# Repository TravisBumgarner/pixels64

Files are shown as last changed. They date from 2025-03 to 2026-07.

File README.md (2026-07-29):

# Pixels64

Pixels64 is an 8x8 grid of 64 individually addressable RGB LEDs using the WS2812B package. It’s powered by an ESP32 running CircuitPython with the neopixel library for control. It features a custom-designed circuit board and a 3D-printable housing.

(Need help? [Join the community](https://discord.com/invite/J8jwMxEEff)!)

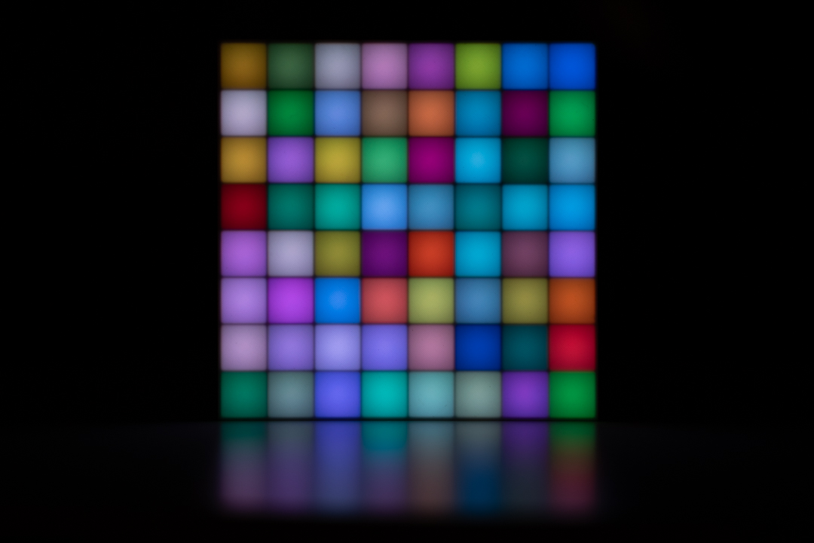
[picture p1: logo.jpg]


This repository includes all the files needed to build the Pixel64 display.

- `cad` - 3D models for housing
- `circuit` - PCB diagram and schematic
- `code` - Code for showing various displays
- `web` - Browser control UI, pairs with `bluetooth-experimental` over Web Bluetooth
- `displays` Collection of displays to get inspired. [Check them out on Instagram](https://www.instagram.com/pixelssixtyfour/).

Additionally

- `my_displays` - What I am currently tinkering on to display.

The PCB is designed to be modular, allowing multiple boards to be combined in an N x M configuration for any display size.

## Setup

### Tools

- Wire cutters
- Soldering Iron

### Components

- esp32
- Three different colors of wire (Red, Black, Blue)
- White Filament
- Black Filament
- 4x pixel64 Boards
- 16x M3x6x4.2 Brass Knurled Nuts
- 16x M3x5 Metal Screws

### Quick Setup

1. Print `base-plate.stl` and `walls.stl` in black. Print `case.stl` in white.
1. Upload files in `jlcpcb` and order from JLCPCB
1. Cut wire to length
   - 3x 25mm Red
   - 3x 25mm Blue
   - 3x 25mm Black
   - 1x 12mm Red
   - 1x 12mm Blue
   - 1x 12mm Black
1. Solder boards together.
   - Blue (data) goes to the center pad. Red (power) to the square pad. Black (power) to the circle pad.
   - Solder the short wires to the `DataIn1` of the first PCB.
   - Solder the long wires from `Dataout1` to the `DataIn1` of the next PCB.
   - Repeat the previous step two more times.
1. Use a soldering iron to press fit the brass knurled nuts into the risers on the `base-plate.stl`.
1. Screw in the boards.
   - Note that all of the boards are oriented with `DataIn1` at the bottom.
   - The arrangement of boards is
   ```
   3 4
   1 2
   ```
1. Setup virtual environment `python -m venv venv` inside the code directory
1. Use virtual environment `source venv/bin/activate
1. Install dependencies `pip install -r requirements.txt`
1. Setup device
   1. Wipe device `esptool.py --chip esp32 --port [device] erase_flash`
   1. [Download MicroPython](https://micropython.org/download/ESP32_GENERIC/) - Your device may be different.
   1. `esptool.py --chip esp32 --port [device] --baud 460800 write_flash -z 0x1000 file.uf2`
1. Run `write.sh` script to upload files to device.
1. Pres the `en` button to shuffle the displays.

## Additional Notes

### CAD

#### Case

- The `case.stl` services as the "screen" of the pixel64. It can be challenging to get a clean print of such a size. You'll need very good first layer adhesion. An alternative here would be to make a case out of white acrylic instead or cover the walls with a white sheet of paper.

### Code

#### Useful commands

- Get a list of connected devices
  - `ls /dev/cu.* /dev/tty.*`
  - The desired device should look something like `tty.usbserial-0001`
- Get a terminal to esp32
  - `mpremote`
  - Note - you can't use the `print` statement while uploading code.
  - Be sure to setup your Python virtual environment before running `mpremote`.
  - `ctrl + ]` to exit
  - `ctrl + c` and `ctrl + d` to soft reboot and cycle through displays.
- Send file to esp32
  - `ampy --port /dev/tty.usbserial-0001 put boot.py`
  - If `put` fails, reconnect device.
  - Push button with "en" to launch code.
- Remove a file
  - `ampy --port /dev/tty.usbserial-0001 rm boot.py`
- List files
  - `ampy --port /dev/tty.usbserial-0001 ls`

### Circuit

#### NeoPixel Mapping

The LED circuit board I designed supports multiple configurations, meaning the default ordering of NeoPixels may not match the expected layout. For example, setting neopixel[0] = (255, 255, 255) won't necessarily light up the top-left LED.

This script cycles through each pixel one at a time, allowing you to determine the actual order. Once identified, we can remap the ordering. For example, the physical layout might be:

```
 3  2  1  0
 7  6  5  4
11 10  9  8
15 14 13 12
```

We can then transform it into a more intuitive sequence:

```
 0  1  2  3
 4  5  6  7
 8  9 10 11
12 13 14 15
```

This remapping ensures easier indexing and consistent control over the LEDs.

Take the following code and save it to `main.py`

```
import machine
import time
import neopixel

NEO_PIXEL_PIN = 13
NEO_PIXEL_COUNT = 64

neo_pin = machine.Pin(NEO_PIXEL_PIN, machine.Pin.OUT)
np = neopixel.NeoPixel(neo_pin, NEO_PIXEL_COUNT)

def set_pixel(i, r, g, b):
    np[i] = (r, g, b)
    np.write()

def main():
    while True:
        for i in range(64):
            set_pixel(i, 255, 0, 0)
            time.sleep_ms(2000)
            set_pixel(i, 0, 0, 0)

if __name__ == "__main__":
    main()

```

Upload the code to the esp32

```
ampy --port [replace with your device] put main.py
```

Place a sheet of paper over the LEDs and tape in place.

Press the `en` button on the esp32 to run the code.

You should see the LEDs light up in a red color.

Mark the first LED that lights up as `0` and complete until done.

Now, starting from the top left, write the numbers of the LEDs in a left to right top to bottom order in the config.py file, replacing the variable `LOOKUP`.

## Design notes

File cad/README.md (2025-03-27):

# CAD

## V1.0 Initial Case Design

The parts were printed on printer with a max printing area of 220mm x 220mm.

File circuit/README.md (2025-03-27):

# Circuit

Each version has two folders inside. 
- `kicad` contains the KiCad project files.
- `jlcpcb` contains the files sent to JLCPCB for order.

## V1.0 Initial PCB Design 

Specs
- Dimension: 100mm x 100mm
- Layers 2
- PCB Thickness: 1.6mm
- PCB Color: Black

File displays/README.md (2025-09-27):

Check out the displays on Instagram: [pixelssixtyfour](https://www.instagram.com/pixelssixtyfour/).

# Displays

## display_gradient_squares

1. Fill display with 2x2 squares of random colors.
1. Repeat:
   1. Pick a random square
   1. Set a target color
   1. Create a gradient from current color to target color.

## display_random_pulses

1. Fill display with 1x1 squares of random colors.
1. Repeat:
   1. Pick a random square
   1. Set square to random color

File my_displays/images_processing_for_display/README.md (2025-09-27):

# Image Display System

This system converts square images into 8x8 color grids for display on your LED matrix.

## Setup

1. **Install Pillow** (for image processing):
   ```bash
   pip install Pillow
   ```

## Usage

### 1. Process Images

1. Place your square images in the `input/` directory
2. Supported formats: JPG, JPEG, PNG, BMP, GIF, TIFF
3. Run the processing script:
   ```bash
   cd src/images
   python3 process_images.py
   ```

This will:

- Resize each image to 8x8 pixels
- Extract RGB color data
- Generate `.py` files in the `output/` directory
- Create an `image_index.py` file listing all processed images

### 2. Display Images

The `display_images.py` file contains a `display_images()` function that:

- Automatically finds all processed images
- Cycles through them every 10 seconds
- Displays each image on your LED matrix

### 3. Integration

To use in your main display system, add this to your `main.py`:

```python
from images.display_images import display_images

displays_to_run = {
    "display_images": display_images,
    # ... other displays
}
```

## File Structure

```
images/
├── input/           # Put your source images here
├── output/          # Generated color data files
│   ├── __init__.py
│   ├── image_index.py  # Auto-generated list of images
│   └── *.py         # Individual image data files
├── process_images.py   # Image processing script
├── display_images.py   # Display function for MicroPython
└── README.md        # This file
```

## Image Processing Details

- Images are resized to 8x8 using high-quality LANCZOS resampling
- RGB values are extracted for each pixel
- Non-square images will be stretched to fit
- Color data is stored as tuples: `(r, g, b)` where each value is 0-255

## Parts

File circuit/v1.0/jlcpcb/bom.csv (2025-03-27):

Comment | Designator | Footprint | JLCPCB Part #
Capacitor_SMD:C_0805_2012Metric | C1,C2,C3,C4,C5,C6,C7,C8,C9,C10,C11,C12,C13,C14,C15,C16 | 0805 | C1711
LED_SMD:LED_WS2812B-Mini_PLCC4_3.5x3.5mm | D1,D2,D3,D4,D5,D6,D7,D8,D9,D10,D11,D12,D13,D14,D15,D16 | 3535 | C527089

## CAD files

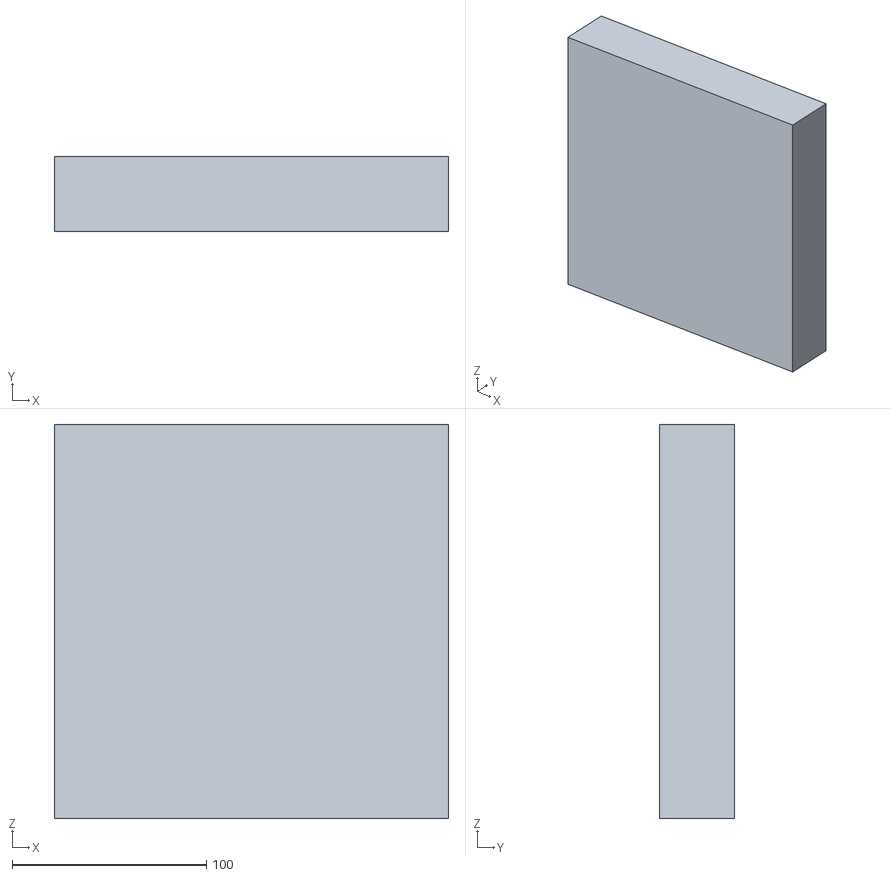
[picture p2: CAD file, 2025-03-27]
cad/v1.0/case.stl
203.0 x 38.5 x 203.0

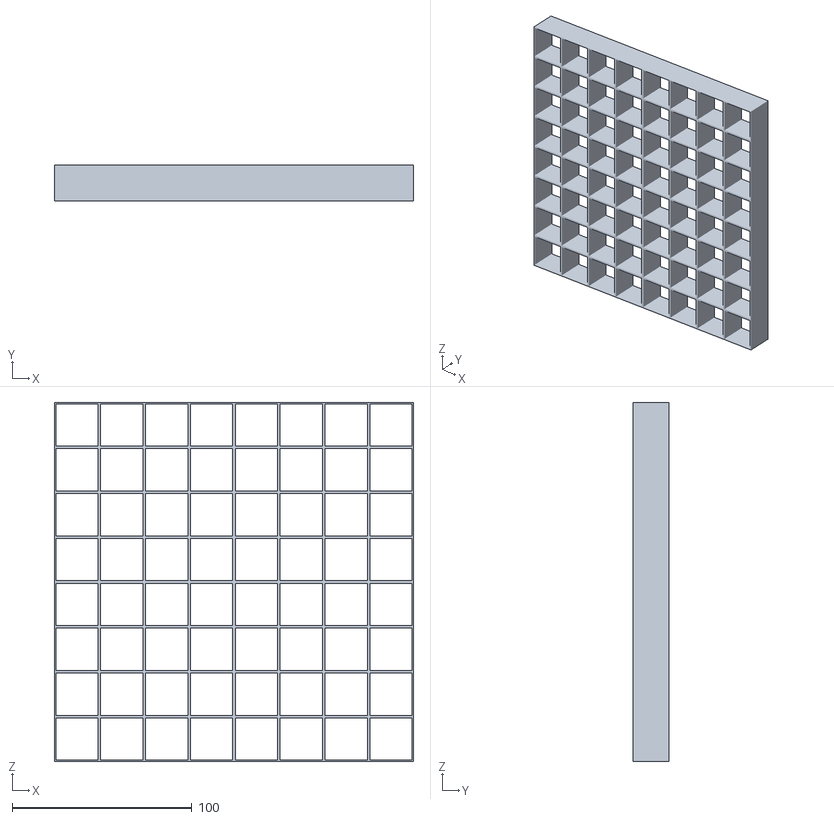
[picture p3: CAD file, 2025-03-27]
cad/v1.0/walls.stl
200.0 x 20.0 x 200.0

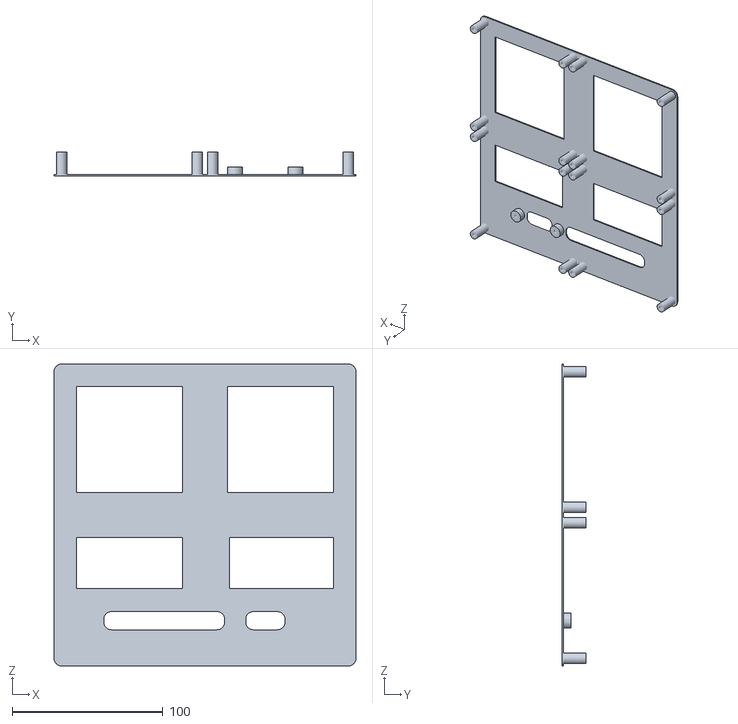
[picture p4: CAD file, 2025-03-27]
cad/v1.0/base-plate.stl
200.0 x 16.0 x 200.0

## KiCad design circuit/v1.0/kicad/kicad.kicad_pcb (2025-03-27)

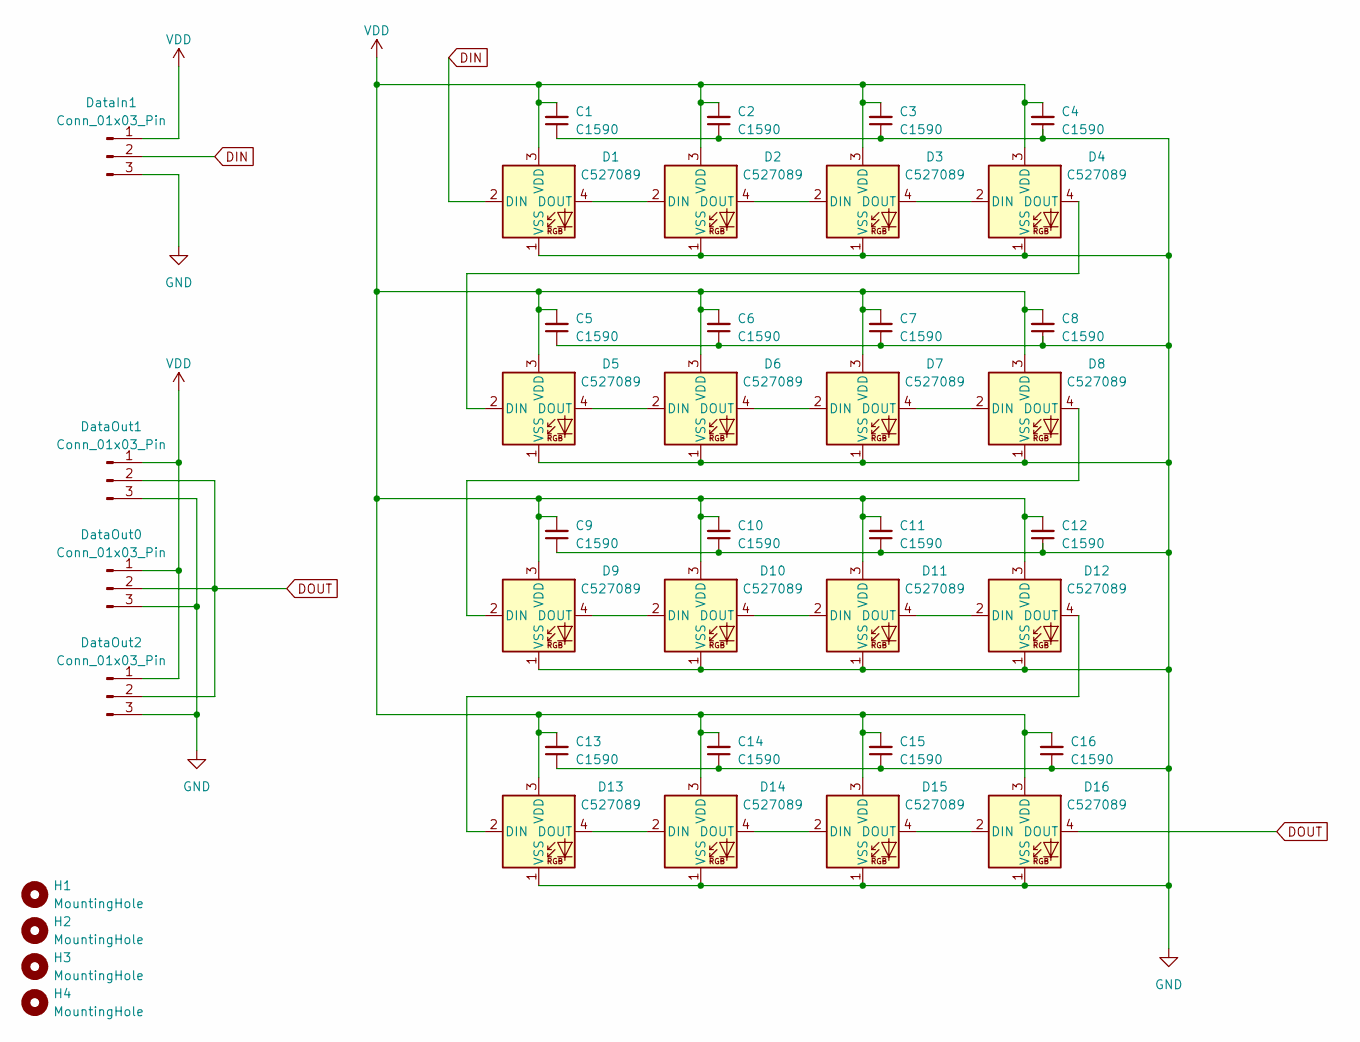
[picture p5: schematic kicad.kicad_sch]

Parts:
C1, C2, C3, C4, C5, C6, C7, C8, C9, C10, C11, C12, C13, C14, C15, C16: C1590; C_0805_2012Metric
D1, D2, D3, D4, D5, D6, D7, D8, D9, D10, D11, D12, D13, D14, D15, D16: C527089; LED_WS2812B-Mini_PLCC4_3.5x3.5mm
DataIn1: Conn_01x03_Pin; PinHeader_1x03_P2.54mm_Vertical
DataOut0, DataOut1, DataOut2: Conn_01x03_Pin; PinHeader_1x03_P2.54mm_Vertical
H1, H2, H3, H4: MountingHole; MountingHole_3.2mm_M3_DIN965_Pad

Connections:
DIN: D1.2 (DIN), DataIn1.2
DOUT: D16.4 (DOUT), DataOut0.2, DataOut1.2, DataOut2.2
GND: C1.1, C2.1, C3.1, C4.1, C5.1, C6.1, C7.1, C8.1, C9.1, C10.1, C11.1, C12.1, C13.1, C14.1, C15.1, C16.1, D1.1 (VSS), D2.1 (VSS), D3.1 (VSS), D4.1 (VSS), D5.1 (VSS), D6.1 (VSS), D7.1 (VSS), D8.1 (VSS), D9.1 (VSS), D10.1 (VSS), D11.1 (VSS), D12.1 (VSS), D13.1 (VSS), D14.1 (VSS), D15.1 (VSS), D16.1 (VSS), DataIn1.3, DataOut0.3, DataOut1.3, DataOut2.3
unnamed: D1.4 (DOUT), D2.2 (DIN)
unnamed: D2.4 (DOUT), D3.2 (DIN)
unnamed: D3.4 (DOUT), D4.2 (DIN)
unnamed: D4.4 (DOUT), D5.2 (DIN)
unnamed: D5.4 (DOUT), D6.2 (DIN)
unnamed: D6.4 (DOUT), D7.2 (DIN)
unnamed: D7.4 (DOUT), D8.2 (DIN)
unnamed: D8.4 (DOUT), D9.2 (DIN)
unnamed: D9.4 (DOUT), D10.2 (DIN)
unnamed: D10.4 (DOUT), D11.2 (DIN)
unnamed: D11.4 (DOUT), D12.2 (DIN)
unnamed: D12.4 (DOUT), D13.2 (DIN)
unnamed: D13.4 (DOUT), D14.2 (DIN)
unnamed: D14.4 (DOUT), D15.2 (DIN)
unnamed: D15.4 (DOUT), D16.2 (DIN)
VDD: C1.2, C2.2, C3.2, C4.2, C5.2, C6.2, C7.2, C8.2, C9.2, C10.2, C11.2, C12.2, C13.2, C14.2, C15.2, C16.2, D1.3 (VDD), D2.3 (VDD), D3.3 (VDD), D4.3 (VDD), D5.3 (VDD), D6.3 (VDD), D7.3 (VDD), D8.3 (VDD), D9.3 (VDD), D10.3 (VDD), D11.3 (VDD), D12.3 (VDD), D13.3 (VDD), D14.3 (VDD), D15.3 (VDD), D16.3 (VDD), DataIn1.1, DataOut0.1, DataOut1.1, DataOut2.1

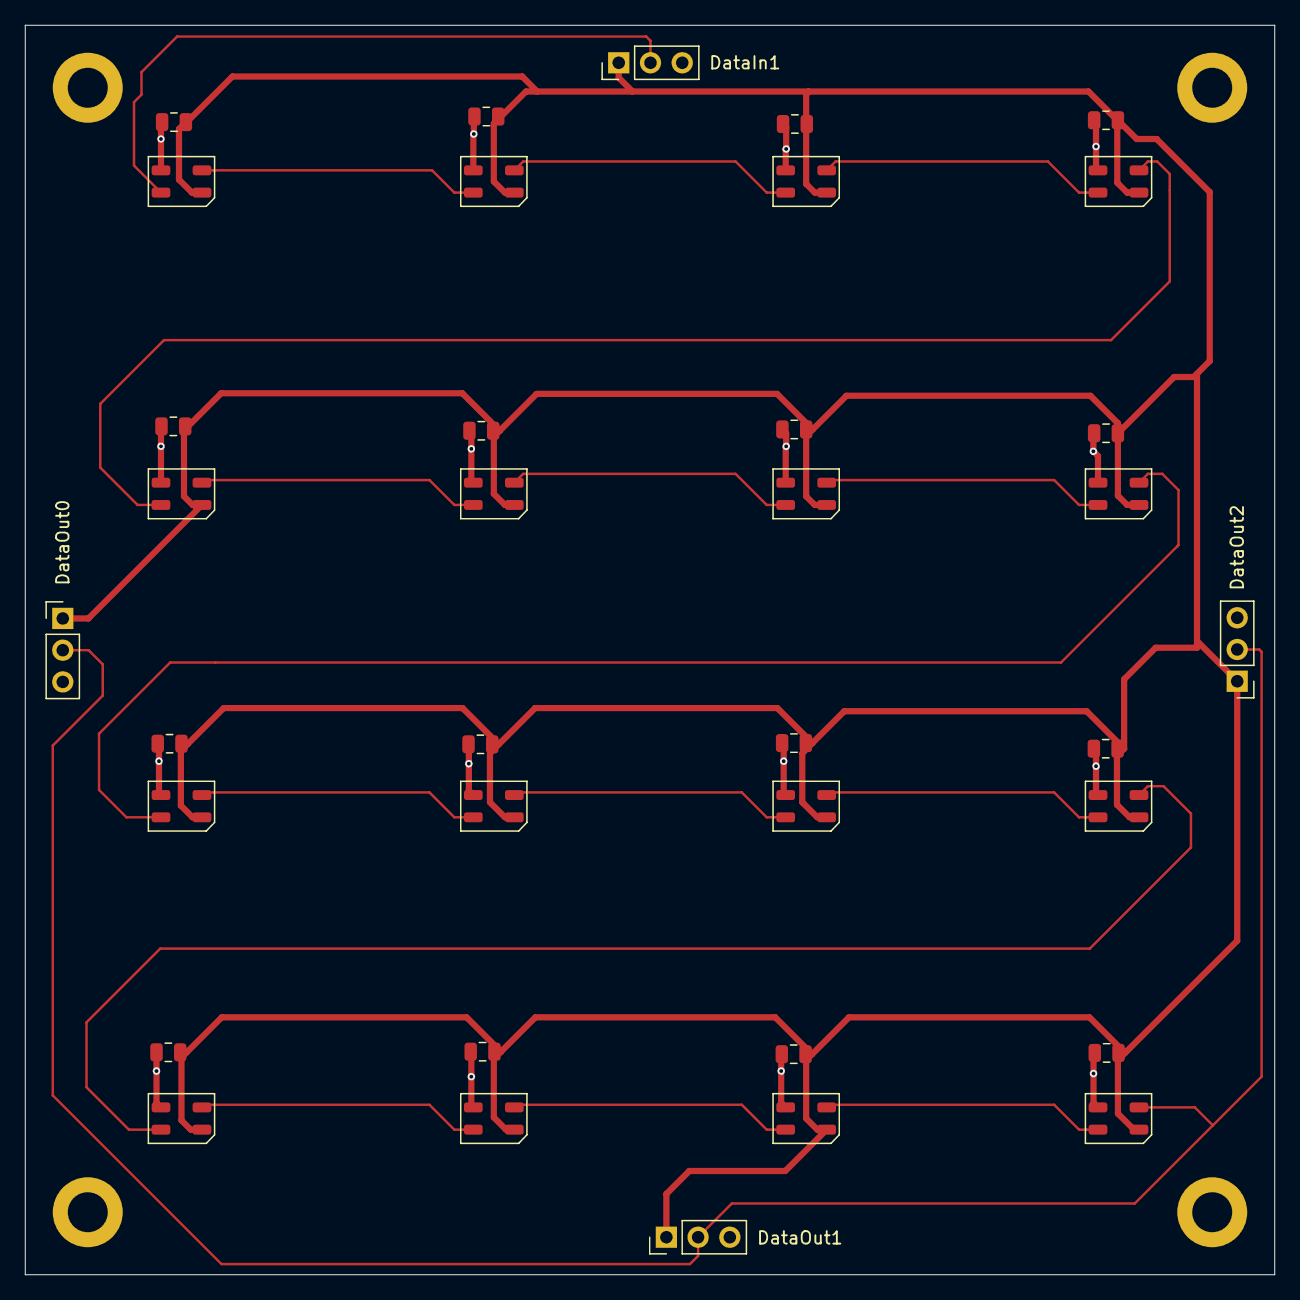
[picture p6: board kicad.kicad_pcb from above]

Board: 2 copper layers, 100.0 x 100.0 mm, 40 parts (0 on the bottom side), 19 nets.

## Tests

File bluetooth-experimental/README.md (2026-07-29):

# bluetooth-experimental

Bluetooth Low Energy (BLE) control for the Pixels64 8×8 NeoPixel display.

An ESP32 running MicroPython advertises a BLE service; a browser-based Web
Bluetooth UI connects to one or more boards and drives the LEDs in real time —
individual pixels, fills, brightness, and animated presets.

This replaces the earlier `wifi-experimental` sandbox (WiFi web server). BLE
avoids needing to put credentials on the device or share a network, and lets the
page talk to several displays at once.

## Layout

```
bluetooth-experimental/
├── src/
│   ├── boot.py       # runs on power-up; disables WiFi to free memory/radio
│   ├── config.py     # LED index lookup tables for the panel wiring
│   ├── presets.py    # animation classes (rainbow, chase, plasma, ...)
│   └── main.py       # BLE GATT server + render loop
├── test_pixel.py     # minimal sanity check — lights one pixel green
└── upload.sh         # flash src/*.py to the board via mpremote
```

This directory holds only the ESP32 firmware. The Web Bluetooth control UI that
drives the board lives in [`../web`](../web) — see
[Run the control UI](#run-the-control-ui) below.

## Requirements

- An ESP32 flashed with MicroPython (with the `bluetooth` module).
- A WS2812/NeoPixel 8×8 panel on GPIO **13**.
- `mpremote` for uploading (`pip install mpremote`).
- A browser that supports **Web Bluetooth** — Chrome or Edge on
  desktop/Android. Safari and iOS are **not** supported.

## Setup

```bash
cd bluetooth-experimental
python3 -m venv venv
source venv/bin/activate
pip install mpremote
```

## Upload firmware to the board

Connect the ESP32 over USB and adjust `PORT` in `upload.sh` if your device
isn't `/dev/tty.usbserial-0001`, then:

```bash
./upload.sh
```

This copies `boot.py`, `config.py`, `presets.py`, and `main.py` to the board and
resets it. On boot it advertises as **`Pixels64`** for a 10-second window
(`BLE_CONNECT_WINDOW_MS`) and lights pixel 0 as a status indicator:

| Indicator | Meaning |
|---|---|
| Green | Advertising, waiting for a connection |
| Blue | A client is connected |
| Red | BLE turned off (connection window expired or client disconnected) |

If no one connects within the window, BLE shuts off to save power. Power-cycle or
reset the board to advertise again. The last running preset is saved to
`active.json` and restored on the next boot.

## Run the control UI

The browser UI lives in [`../web`](../web). It's a single static file, so
serving it locally needs no toolchain:

```bash
cd web
npm run dev
```

`localhost` counts as a secure context, which the Web Bluetooth API requires —
no certificate needed. A LAN address would not work; in production the page sits
behind a reverse proxy that terminates TLS.

Open <http://localhost:8000> in Chrome or Edge (Safari does **not** support Web
Bluetooth), click **+ Add device**, and pick your `Pixels64` board from the BLE
chooser. You can add multiple boards. The UI provides a paintable 8×8 grid,
color picker, fill/clear, brightness and FPS sliders, and the preset list.

## BLE protocol

A single writable characteristic accepts short binary command packets. Service
and characteristic UUIDs are defined in `main.py`; the first byte is the opcode:

| Opcode | Name | Payload |
|---|---|---|
| `0x01` | SET_PIXEL | `idx, r, g, b` |
| `0x02` | FILL | `r, g, b` |
| `0x03` | CLEAR | — |
| `0x05` | PRESET | `index` (into `PRESET_ORDER`) |
| `0x06` | BRIGHTNESS | `0–255` |
| `0x07` | BATCH | `count`, then `count`×`idx,r,g,b`|
| `0x08` | STOP | — (stop the running animation) |
| `0x09` | FPS | `1–30` |

Pixel indices are logical positions (0–63, row-major); `config.py`'s `LOOKUP`
table maps them to the panel's physical wiring order.

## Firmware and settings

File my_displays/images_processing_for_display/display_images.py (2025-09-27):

import time
import machine
import neopixel
import sys

# Add parent directory to path to import config
sys.path.append("..")
from config import get_led_index

NEO_PIXEL_PIN = 13
NEO_PIXEL_COUNT = 64

neo_pin = machine.Pin(NEO_PIXEL_PIN, machine.Pin.OUT)
np = neopixel.NeoPixel(neo_pin, NEO_PIXEL_COUNT)

# ============================================================================
# PASTE GENERATED IMAGE DATA HERE (from generated_images.txt)
# ============================================================================

# Example placeholder - replace with your generated data
# Generated image data - Copy this into display_images.py
# Replace the existing IMAGES dictionary with this code:

# From 01-2022-06-05 11.48.28
a01_2022_06_05_11_48_28 = [
    [
        (46, 23, 16),
        (110, 70, 38),
        (164, 110, 55),
        (101, 66, 40),
        (121, 104, 96),
        (131, 117, 104),
        (140, 130, 119),
        (120, 108, 100),
    ],
    [
        (41, 33, 37),
        (126, 103, 95),
        (113, 84, 72),
        (89, 58, 44),
        (77, 50, 29),
        (123, 100, 84),
        (155, 137, 115),
        (144, 138, 128),
    ],
    [
        (24, 25, 32),
        (161, 143, 130),
        (171, 157, 145),
        (117, 98, 90),
        (57, 45, 51),
        (88, 73, 65),
        (80, 91, 89),
        (95, 75, 64),
    ],
    [
        (31, 11, 10),
        (145, 153, 154),
        (187, 195, 194),
        (123, 106, 100),
        (90, 45, 37),
        (85, 60, 48),
        (83, 68, 53),
        (57, 25, 15),
    ],
    [
        (22, 4, 3),
        (111, 96, 90),
        (164, 143, 134),
        (118, 103, 98),
        (80, 55, 30),
        (99, 88, 72),
        (69, 84, 72),
        (46, 22, 17),
    ],
    [
        (23, 17, 9),
        (93, 89, 85),
        (108, 107, 105),
        (114, 109, 107),
        (77, 73, 69),
        (81, 62, 55),
        (58, 49, 52),
        (54, 41, 36),
    ],
    [
        (24, 17, 9),
        (57, 57, 55),
        (101, 95, 92),
        (114, 104, 99),
        (66, 41, 37),
        (33, 16, 16),
        (78, 69, 62),
        (72, 61, 54),
    ],
    [
        (16, 9, 9),
        (47, 40, 39),
        (132, 117, 109),
        (89, 72, 63),
        (37, 17, 13),
        (26, 15, 14),
        (56, 66, 79),
        (58, 52, 51),
    ],
]

# From 03-000070120029
a03_000070120029 = [
    [
        (88, 79, 71),
        (102, 87, 83),
        (103, 100, 100),
        (99, 114, 118),
        (100, 127, 132),
        (105, 141, 143),
        (114, 153, 151),
        (116, 159, 154),
    ],
    [
        (91, 86, 86),
        (96, 99, 105),
        (98, 118, 130),
        (101, 136, 147),
        (110, 155, 161),
        (122, 172, 173),
        (137, 185, 180),
        (143, 192, 184),
    ],
    [
        (94, 97, 101),
        (95, 118, 128),
        (102, 131, 138),
        (111, 153, 159),
        (124, 175, 178),
        (138, 186, 181),
        (154, 197, 191),
        (159, 200, 193),
    ],
    [
        (95, 99, 94),
        (102, 152, 170),
        (122, 155, 150),
        (124, 161, 156),
        (133, 190, 192),
        (141, 185, 180),
        (160, 204, 200),
        (167, 211, 206),
    ],
    [
        (86, 59, 34),
        (86, 91, 84),
        (124, 121, 100),
        (160, 109, 56),
        (153, 117, 73),
        (156, 121, 74),
        (171, 133, 81),
        (161, 130, 84),
    ],
    [
        (86, 60, 39),
        (82, 54, 33),
        (100, 65, 36),
        (126, 80, 40),
        (123, 74, 34),
        (121, 73, 33),
        (118, 72, 32),
        (115, 69, 31),
    ],
    [
        (88, 60, 39),
        (90, 62, 42),
        (88, 61, 42),
        (85, 58, 41),
        (85, 59, 42),
        (85, 59, 43),
        (87, 59, 42),
        (88, 60, 43),
    ],
    [
        (93, 65, 45),
        (95, 68, 48),
        (90, 60, 43),
        (92, 61, 43),
        (93, 63, 44),
        (93, 64, 44),
        (93, 62, 43),
        (93, 62, 43),
    ],
]

# From 05-2022-09-14 18.13.48
a05_2022_09_14_18_13_48 = [
    [
        (71, 110, 135),
        (114, 141, 164),
        (148, 171, 193),
        (158, 180, 202),
        (156, 178, 201),
        (164, 189, 212),
        (164, 187, 207),
        (172, 196, 212),
    ],
    [
        (107, 135, 157),
        (134, 156, 178),
        (143, 164, 186),
        (181, 195, 208),
        (179, 194, 208),
        (169, 188, 205),
        (188, 203, 217),
        (177, 196, 211),
    ],
    [
        (92, 123, 146),
        (77, 115, 142),
        (135, 156, 176),
        (194, 201, 209),
        (168, 182, 196),
        (132, 155, 176),
        (97, 131, 158),
        (79, 118, 147),
    ],
    [
        (77, 111, 133),
        (62, 102, 126),
        (46, 92, 123),
        (59, 103, 134),
        (55, 99, 132),
        (27, 86, 121),
        (24, 83, 118),
        (31, 84, 117),
    ],
    [
        (101, 127, 148),
        (115, 135, 156),
        (112, 134, 155),
        (105, 130, 153),
        (108, 131, 153),
        (109, 133, 154),
        (107, 132, 153),
        (103, 127, 149),
    ],
    [
        (100, 125, 145),
        (98, 124, 145),
        (103, 126, 148),
        (108, 128, 150),
        (108, 129, 150),
        (111, 132, 153),
        (105, 128, 149),
        (95, 122, 143),
    ],
    [
        (92, 119, 140),
        (91, 120, 141),
        (89, 116, 139),
        (88, 116, 138),
        (88, 115, 138),
        (93, 119, 141),
        (86, 115, 137),
        (77, 109, 132),
    ],
    [
        (55, 93, 119),
        (68, 101, 126),
        (83, 112, 133),
        (86, 114, 136),
        (83, 111, 134),
        (82, 112, 133),
        (72, 105, 128),
        (66, 101, 125),
    ],
]

# From 04-DJI_0089
a04_DJI_0089 = [
    [
        (0, 112, 77),
        (0, 114, 73),
        (0, 116, 75),
        (0, 114, 74),
        (0, 112, 68),
        (1, 111, 69),
        (1, 110, 74),
        (0, 110, 80),
    ],
    [
        (0, 118, 79),
        (0, 118, 76),
        (0, 123, 79),
        (0, 119, 76),
        (1, 122, 79),
        (1, 118, 81),
        (1, 113, 75),
        (2, 111, 79),
    ],
    [
        (17, 126, 84),
        (12, 131, 82),
        (3, 135, 82),
        (0, 132, 80),
        (0, 131, 84),
        (1, 123, 84),
        (1, 116, 79),
        (3, 120, 84),
    ],
    [
        (51, 124, 86),
        (40, 128, 84),
        (26, 132, 84),
        (24, 140, 90),
        (18, 140, 91),
        (6, 129, 82),
        (5, 119, 83),
        (4, 119, 88),
    ],
    [
        (80, 127, 104),
        (54, 124, 87),
        (39, 123, 82),
        (26, 124, 81),
        (33, 130, 89),
        (29, 129, 89),
        (23, 125, 85),
        (19, 120, 86),
    ],
    [
        (186, 182, 174),
        (100, 132, 112),
        (38, 103, 68),
        (20, 98, 66),
        (23, 111, 81),
        (31, 117, 91),
        (36, 119, 87),
        (46, 124, 86),
    ],
    [
        (219, 214, 210),
        (209, 199, 192),
        (126, 138, 122),
        (63, 100, 75),
        (44, 94, 69),
        (37, 100, 77),
        (36, 110, 90),
        (41, 114, 91),
    ],
    [
        (187, 197, 202),
        (217, 213, 209),
        (223, 212, 203),
        (166, 165, 154),
        (101, 122, 104),
        (67, 105, 81),
        (47, 101, 82),
        (47, 108, 93),
    ],
]

# From 06-DSC_0711
a06_DSC_0711 = [
    [
        (118, 48, 1),
        (130, 56, 3),
        (143, 68, 23),
        (146, 73, 35),
        (141, 69, 26),
        (154, 77, 30),
        (161, 83, 35),
        (164, 89, 42),
    ],
    [
        (118, 48, 1),
        (128, 53, 0),
        (142, 67, 20),
        (145, 72, 34),
        (137, 63, 19),
        (150, 73, 24),
        (158, 80, 31),
        (157, 82, 35),
    ],
    [
        (117, 46, 1),
        (128, 52, 0),
        (140, 65, 19),
        (141, 68, 30),
        (132, 59, 13),
        (147, 70, 21),
        (153, 75, 26),
        (154, 79, 32),
    ],
    [
        (114, 45, 1),
        (124, 50, 0),
        (133, 60, 15),
        (136, 64, 24),
        (130, 58, 9),
        (139, 63, 13),
        (146, 69, 19),
        (147, 73, 26),
    ],
    [
        (109, 41, 1),
        (117, 45, 0),
        (120, 52, 10),
        (123, 55, 13),
        (122, 51, 2),
        (125, 55, 6),
        (136, 62, 11),
        (135, 64, 16),
    ],
    [
        (100, 37, 2),
        (103, 36, 0),
        (120, 63, 22),
        (152, 114, 72),
        (134, 87, 46),
        (115, 50, 6),
        (127, 57, 6),
        (121, 55, 7),
    ],
    [
        (90, 31, 2),
        (90, 29, 0),
        (111, 60, 25),
        (126, 85, 51),
        (99, 41, 10),
        (109, 44, 1),
        (115, 51, 3),
        (109, 49, 3),
    ],
    [
        (79, 25, 1),
        (84, 29, 1),
        (81, 27, 1),
        (79, 23, 0),
        (90, 31, 0),
        (101, 41, 1),
        (105, 45, 1),
        (100, 45, 2),
    ],
]

# From 01-DJI_0276
a01_DJI_0276 = [
    [
        (74, 146, 208),
        (62, 139, 203),
        (53, 132, 199),
        (46, 126, 194),
        (39, 121, 189),
        (31, 115, 184),
        (26, 111, 179),
        (25, 110, 177),
    ],
    [
        (99, 164, 220),
        (85, 156, 216),
        (72, 148, 212),
        (61, 141, 206),
        (54, 135, 202),
        (50, 131, 198),
        (47, 128, 195),
        (43, 125, 192),
    ],
    [
        (128, 183, 230),
        (118, 178, 228),
        (105, 171, 224),
        (98, 170, 224),
        (88, 164, 221),
        (75, 153, 212),
        (70, 148, 209),
        (66, 144, 206),
    ],
    [
        (178, 221, 253),
        (169, 216, 250),
        (162, 214, 250),
        (142, 194, 231),
        (131, 186, 226),
        (140, 200, 241),
        (130, 190, 234),
        (124, 185, 230),
    ],
    [
        (137, 158, 175),
        (144, 163, 179),
        (146, 165, 180),
        (113, 129, 143),
        (116, 133, 146),
        (157, 173, 182),
        (154, 170, 179),
        (153, 169, 178),
    ],
    [
        (103, 103, 101),
        (116, 112, 108),
        (122, 118, 114),
        (123, 120, 115),
        (130, 126, 120),
        (143, 139, 132),
        (144, 141, 134),
        (134, 133, 129),
    ],
    [
        (134, 132, 127),
        (148, 145, 139),
        (155, 152, 147),
        (149, 142, 133),
        (148, 140, 129),
        (154, 146, 132),
        (157, 147, 130),
        (137, 131, 119),
    ],
    [
        (157, 158, 152),
        (151, 149, 142),
        (152, 147, 138),
        (168, 163, 153),
        (166, 162, 152),
        (161, 154, 140),
        (160, 153, 136),
        (155, 147, 129),
    ],
]

# From 02-Foto-21
a02_FOTO_21 = [
    [
        (22, 24, 19),
        (21, 24, 19),
        (41, 40, 43),
        (72, 63, 85),
        (65, 59, 81),
        (110, 102, 126),
        (189, 182, 193),
        (212, 205, 211),
    ],
    [
        (65, 61, 69),
        (51, 50, 54),
        (62, 58, 69),
        (65, 60, 81),
        (58, 56, 76),
        (51, 47, 67),
        (127, 124, 138),
        (187, 181, 191),
    ],
    [
        (95, 91, 104),
        (82, 79, 92),
        (60, 61, 69),
        (97, 92, 103),
        (98, 92, 99),
        (181, 169, 172),
        (246, 229, 233),
        (233, 218, 222),
    ],
    [
        (119, 114, 128),
        (108, 98, 115),
        (91, 81, 98),
        (145, 128, 145),
        (121, 108, 116),
        (194, 181, 184),
        (210, 199, 206),
        (183, 179, 184),
    ],
    [
        (87, 85, 106),
        (171, 160, 175),
        (215, 204, 214),
        (238, 227, 231),
        (227, 219, 220),
        (216, 209, 211),
        (181, 179, 184),
        (222, 222, 222),
    ],
    [
        (92, 87, 94),
        (232, 223, 225),
        (220, 222, 217),
        (133, 138, 135),
        (139, 145, 142),
        (240, 237, 235),
        (255, 255, 255),
        (255, 255, 253),
    ],
    [
        (186, 164, 172),
        (167, 148, 156),
        (62, 60, 61),
        (111, 112, 112),
        (99, 100, 100),
        (114, 117, 114),
        (211, 205, 204),
        (198, 192, 190),
    ],
    [
        (202, 171, 184),
        (149, 122, 134),
        (80, 72, 75),
        (126, 122, 125),
        (122, 118, 119),
        (58, 55, 55),
        (77, 70, 70),
        (74, 67, 67),
    ],
]

# From 07-DSC08342
a07_DSC08342 = [
    [
        (83, 94, 112),
        (88, 105, 128),
        (82, 100, 122),
        (82, 96, 112),
        (103, 60, 13),
        (110, 59, 2),
        (134, 85, 1),
        (108, 66, 6),
    ],
    [
        (125, 157, 196),
        (126, 159, 194),
        (68, 82, 86),
        (73, 76, 75),
        (47, 24, 25),
        (42, 12, 7),
        (180, 123, 25),
        (176, 128, 26),
    ],
    [
        (157, 189, 228),
        (152, 186, 221),
        (97, 120, 127),
        (110, 118, 119),
        (54, 30, 27),
        (51, 19, 10),
        (210, 158, 53),
        (222, 180, 62),
    ],
    [
        (149, 178, 208),
        (144, 176, 202),
        (104, 131, 140),
        (120, 131, 135),
        (60, 30, 27),
        (55, 16, 8),
        (169, 94, 39),
        (171, 103, 42),
    ],
    [
        (151, 180, 215),
        (149, 179, 210),
        (104, 136, 146),
        (123, 134, 140),
        (58, 28, 25),
        (49, 10, 4),
        (125, 17, 11),
        (118, 14, 10),
    ],
    [
        (155, 186, 222),
        (153, 187, 219),
        (123, 151, 162),
        (137, 143, 147),
        (71, 29, 26),
        (65, 16, 9),
        (131, 23, 9),
        (127, 23, 12),
    ],
    [
        (124, 153, 178),
        (119, 150, 175),
        (199, 205, 206),
        (190, 181, 178),
        (115, 35, 28),
        (131, 39, 27),
        (122, 22, 14),
        (125, 24, 16),
    ],
    [
        (138, 109, 115),
        (145, 116, 120),
        (186, 159, 156),
        (164, 144, 130),
        (142, 87, 74),
        (158, 106, 93),
        (155, 102, 96),
        (154, 96, 94),
    ],
]

IMAGES = {
    "01-2022-06-05 11.48.28": a01_2022_06_05_11_48_28,
    "03-000070120029": a03_000070120029,
    "05-2022-09-14 18.13.48": a05_2022_09_14_18_13_48,
    "04-DJI_0089": a04_DJI_0089,
    "06-DSC_0711": a06_DSC_0711,
    "01-DJI_0276": a01_DJI_0276,
    "02-Foto-21": a02_FOTO_21,
    "07-DSC08342": a07_DSC08342,
}

# ============================================================================


def display_image(color_grid):
    """Display a single 8x8 color grid on the LED matrix."""
    if not color_grid:
        return

    for y in range(8):
        for x in range(8):
            if y < len(color_grid) and x < len(color_grid[y]):
                color = color_grid[y][x]
                led_index = get_led_index(y, x)
                if led_index is not None:
                    np[led_index] = color

    np.write()


def display_images():
    """Main display function that cycles through all available images."""
    if not IMAGES:
        print(
            "No images found! Please run process_images.py and copy the generated code."
        )
        # Display a simple pattern to show the display is working
        for i in range(64):
            np[i] = (32, 32, 32)  # Dim white
        np.write()
        return

    image_names = list(IMAGES.keys())
    print(f"Found {len(image_names)} images to display")

    current_index = 0

    while True:
        image_name = image_names[current_index]
        print(f"Displaying: {image_name}")

        # Display the image
        color_grid = IMAGES[image_name]
        display_image(color_grid)

        # Wait 10 seconds before switching to next image
        time.sleep(10)

        # Move to next image (cycle back to start when done)
        current_index = (current_index + 1) % len(image_names)


if __name__ == "__main__":
    display_images()

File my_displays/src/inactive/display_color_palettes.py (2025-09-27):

import random
import time

import machine
import neopixel
from config import LOOKUP
from common import NEO_PIXEL_COUNT, NEO_PIXEL_PIN

neo_pin = machine.Pin(NEO_PIXEL_PIN, machine.Pin.OUT)
np = neopixel.NeoPixel(neo_pin, NEO_PIXEL_COUNT)


GRID_SIDE = 8

PALETTES = [
    ["#949088", "#34373b", "#d5d7d5", "#1179aa", "#c89a00", "#8f1c27"],
    ["#6f6e6d", "#387286", "#434c4e", "#c0b7ae", "#232528", "#969492"],
    ["#e7711c", "#c9beae", "#5595b2", "#dbe2d9", "#5d5d60", "#251c1b"],
    ["#5ab4e2", "#6d6d6e", "#252f32", "#aea79c", "#b28e53", "#2c7878"],
    ["#5d1f1b", "#594a43", "#8c8886", "#432522", "#87624d", "#130e0c"],
    ["#acfbfe", "#c39417", "#98948e", "#2d3344", "#61747f", "#d0c7ba"],
    ["#ac5320", "#e2eef7", "#484043", "#2e0d1c", "#417eba", "#979a98"],
    ["#5d5751", "#077975", "#2f3937", "#181111", "#6a553a", "#ccdeeb"],
    ["#d1695a", "#202726", "#aea190", "#9ebbc8", "#7e6960", "#473832"],
    ["#2c3436", "#5f5e7b", "#e1e7ee", "#435f69", "#30454b", "#57898d"],
    ["#6889a8", "#eee6dd", "#332e20", "#e2deb6", "#776d58", "#b4a688"],
    ["#70492c", "#19110d", "#88949e", "#342e2b", "#340e0b", "#534f4d"],
    ["#344b5d", "#e095b9", "#b7afb0", "#2271ca", "#d5cdcf", "#8f8382"],
    ["#b57e74", "#c5b6ae", "#99857f", "#3c3232", "#d1cdd0", "#746966"],
    ["#2d925e", "#b88233", "#797876", "#cac5c2", "#2b2d28", "#864940"],
    ["#7be0eb", "#8d4a55", "#e2bd51", "#1b1e20", "#4e4e49", "#afafaa"],
    ["#dde2ea", "#7e9bb3", "#1e1917", "#acada8", "#bf8c44", "#625f5a"],
    ["#a6b7bf", "#2f3232", "#afd1ea", "#727a7f", "#515353", "#94a3ad"],
    ["#662b30", "#90817e", "#914e4a", "#260b13", "#bdada4", "#ad3870"],
    ["#e6c785", "#899da2", "#384a47", "#d0a353", "#bfc5c8", "#558187"],
    ["#9b3533", "#241b21", "#566b62", "#b3b5a8", "#5b3f3c", "#ddded3"],
    ["#332933", "#f1b0bc", "#a75f8a", "#dbdde1", "#c96590", "#a95f9a"],
    ["#62c795", "#c49647", "#f7939c", "#323f4d", "#e0f9f6", "#94c5c2"],
    ["#566eac", "#693f19", "#221d2f", "#a0a7b0", "#f1b326", "#465685"],
    ["#c2966b", "#6b503d", "#9c6437", "#c8b7a7", "#87705e", "#2f2829"],
    ["#c4c9d3", "#262022", "#815a49", "#b7bbc4", "#aaa096", "#d3d7de"],
    ["#6bb391", "#10412c", "#979795", "#d3d9db", "#6c4234", "#b0554d"],
    ["#a2502e", "#927352", "#dfe3ec", "#32384a", "#d4b64b", "#5d75a2"],
    ["#d3b741", "#98452f", "#e1d7d5", "#3b3027", "#9a8a71", "#635442"],
    ["#4f8a5f", "#e3ab68", "#364146", "#824246", "#b2885d", "#f8e3c0"],
    ["#4bb6be", "#bcafaa", "#9b958e", "#847265", "#b1a39e", "#212125"],
    ["#95606e", "#0c6e82", "#00512b", "#7e563b", "#bdbec1", "#8f3d37"],
    ["#765e7d", "#281411", "#e2e6ea", "#5e160e", "#4f4349", "#6a93a7"],
    ["#959998", "#3b373e", "#c0d1dd", "#1a1818", "#727472", "#76551e"],
    ["#cbb3a0", "#70696a", "#373438", "#a18f85", "#7d7a7e", "#575254"],
    ["#806259", "#a89c8f", "#577385", "#639abb", "#c5b4a1", "#353f48"],
    ["#3c2627", "#b6afaa", "#dbdfe2", "#5c6061", "#d5d1ca", "#9d3335"],
    ["#c58e76", "#fde690", "#8fae8b", "#64543b", "#dfc89c", "#8f7a5b"],
    ["#dbccc2", "#8f4738", "#c48d26", "#344962", "#c3b186", "#987c58"],
    ["#98c0b0", "#413c39", "#f0e6d6", "#848285", "#bcaba4", "#bbcfc6"],
    ["#5a5453", "#332a20", "#dad5d0", "#b37610", "#610f01", "#075676"],
    ["#d7d0cc", "#926e35", "#414433", "#aa8a50", "#bea794", "#e4b2a7"],
    ["#8798b6", "#827978", "#357878", "#4b2635", "#5c5652", "#6796a8"],
    ["#cca153", "#212221", "#7cb3cc", "#e3dad0", "#2c5252", "#867653"],
    ["#783220", "#bdbfc4", "#205677", "#b8984f", "#9e978d", "#1c2026"],
    ["#abbdcf", "#155480", "#64574f", "#96a9b9", "#7e8485", "#162535"],
    ["#c46f55", "#516066", "#111721", "#c9c8c4", "#3f85b7", "#363d3a"],
    ["#cb8c68", "#5c5b58", "#ddb18b", "#cd8878", "#86827b", "#353637"],
    ["#bebcbc", "#634731", "#88a2b4", "#332111", "#b99482", "#8f3e2f"],
    ["#a37f32", "#65615f", "#a6a5a5", "#342a23", "#8b6826", "#1f5873"],
    ["#4ba4c0", "#58514c", "#c4b9bd", "#a02d55", "#e3e4db", "#27281b"],
    ["#b9ad79", "#997e65", "#8eacc8", "#a18a98", "#86a99b", "#1b1619"],
    ["#909aba", "#dbd8d8", "#3e361e", "#998e85", "#c1b9b8", "#6e6150"],
    ["#353231", "#030c0d", "#62494b", "#686e6f", "#1b1a1a", "#553f3f"],
    ["#cfc1b5", "#69645a", "#98a1b1", "#1b1b24", "#b88e6f", "#f1f3f4"],
    ["#e8c2bf", "#f1da9f", "#ffac80", "#817063", "#fac650", "#ff792b"],
    ["#8cc3c4", "#102422", "#787473", "#454548", "#79b3b4", "#c4bcc9"],
    ["#da9d9c", "#3e3633", "#b67a33", "#7f8d97", "#725d4c", "#be8882"],
    ["#48583b", "#818a74", "#b5bfc9", "#3d3830", "#656956", "#94704c"],
    ["#f0bad1", "#2096ad", "#11100d", "#e0c99e", "#2a7480", "#679eaa"],
    ["#9b1624", "#db9621", "#e7c84f", "#96c28f", "#59b2de", "#9689a7"],
    ["#ae896e", "#718365", "#b16734", "#dcc6b9", "#64462f", "#455177"],
    ["#b89764", "#504842", "#365c8b", "#afada8", "#837263", "#6694ac"],
    ["#a08f82", "#2b5d43", "#f1eceb", "#86c5ba", "#646e5b", "#bdcecb"],
    ["#707077", "#32211a", "#a58f88", "#c0c2c2", "#946d64", "#61504b"],
    ["#846c5a", "#d2d1cf", "#216497", "#8fa1ae", "#323235", "#4d86b2"],
    ["#85888a", "#8a8e92", "#546f63", "#222929", "#7d7f82", "#1b1a19"],
    ["#a7b1a9", "#6d6a65", "#2d2923", "#c1d0c7", "#4e4a43", "#8d908a"],
    ["#a0bca1", "#44281c", "#dddcd4", "#172828", "#9bae96", "#211b19"],
    ["#e9d3ab", "#c0966e", "#34544c", "#3b3a28", "#887362", "#76a18e"],
    ["#b69e75", "#669fb5", "#77797b", "#704b47", "#9d5f5b", "#232828"],
    ["#5c663a", "#98a7ba", "#73808c", "#253431", "#ced9e1", "#0885af"],
    ["#a49a95", "#a7ab9a", "#f4f5f6", "#3c312c", "#a57163", "#ccc8bb"],
    ["#262928", "#8f9376", "#9d5935", "#5f5e48", "#0877b3", "#cf9240"],
    ["#c27b69", "#9dafb9", "#3768b3", "#1a1f25", "#5c5f68", "#2d3b4a"],
    ["#e9dc87", "#cfb789", "#222b32", "#cdd5d7", "#a7938a", "#478b68"],
    ["#d1c8ba", "#47473d", "#17191b", "#b6a413", "#b68586", "#0c80a8"],
    ["#c6b7bc", "#372a2b", "#6c5052", "#b79baa", "#d6cbcf", "#90777c"],
    ["#ceaf6a", "#33221b", "#d2d4d5", "#637361", "#b8b5a9", "#8a9886"],
    ["#5a996f", "#e8ce94", "#2d2b29", "#81786f", "#bc8c69", "#e9eaea"],
    ["#94b8c2", "#4e5d5b", "#9e897d", "#161a19", "#bb7e1e", "#67929a"],
    ["#97482d", "#ded9d6", "#bb603c", "#435960", "#6a8e98", "#ecbc85"],
    ["#e3a5ac", "#0eb2ec", "#eeebe8", "#c8a76b", "#5b6976", "#93888e"],
    ["#eee1cd", "#e8dddc", "#db8979", "#413528", "#b1452d", "#cbb9ac"],
    ["#7f8671", "#47503e", "#d3ccc6", "#6b6c57", "#cda597", "#aa6835"],
    ["#7b8da5", "#5d0b15", "#76705f", "#1c1b21", "#3c7b9b", "#996920"],
    ["#dfe0d9", "#e8c58e", "#292620", "#378d9c", "#575a53", "#b6b3a9"],
    ["#4c7d96", "#153140", "#474a3b", "#1f221d", "#f6cb75", "#c44840"],
    ["#7e6231", "#33436c", "#675948", "#491d0d", "#514439", "#8d8b86"],
    ["#f8b641", "#584f50", "#2a2727", "#c2bebc", "#a07066", "#ad4d44"],
    ["#b0b8c2", "#38434e", "#718191", "#949ca5", "#556474", "#1a1e23"],
    ["#c4cdd6", "#816b5f", "#ca7c52", "#3f6067", "#a19a97", "#002e72"],
    ["#4e2d3d", "#cda897", "#7fb0a1", "#696569", "#e5dcd8", "#a98572"],
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

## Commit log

2025-01-25 added button
2025-03-27 Documentation, Initial Displays, PCB Files (#3)
    * bunch of docs
    * better write script
    * docs and log
    * added random cycle on boot
    * having fun with what AI gives me
    * fun displays
    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
    [bom.csv, kicad.kicad_pcb, kicad.kicad_sch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]
2025-03-27 Full Documentation (#4)
    * added cad files
    * better readmes and misc cleanup
    * cleanup
    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
    [base-plate.stl, case.stl, walls.stl]
2025-04-17 Notes for new devices(#10)
    * min reqs
    * remaining bits
2026-06-21 Replace wifi-experimental sandbox with bluetooth-experimental (#15)
    * Add wifi-experimental sandbox: WiFi web UI for pixel control
    ESP32 STA-mode HTTP server with grid paint, 17 frame-based preset animations
    (ported from existing my_displays code), custom code endpoint with safety
    harness, and runtime FPS + brightness sliders. RMT driver bypasses bitbang
    CPU jitter on the unicore firmware.
    * Idle shutoff and active-state persistence
    Server marks activity on every request and clears LEDs after 30s of silence
    (animation pauses, resumes on next request). Frontend polls /state every 5s
    as keepalive. Active preset/custom cod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
    [config.py, main.py, presets.py]
2026-07-10 Remove duplicate web UI; persist brightness/FPS across reboots (#16)
    The Web Bluetooth control UI now lives in the rasppi-utils repo, so drop the
    byte-identical copy and the serve.sh dev shim from bluetooth-experimental and
    point the README at the rasppi-utils repo with local-serve instructions.
    Also persist brightness and tick_ms (FPS) to active.json and restore them on
    boot, so they no longer reset to defaults on a fresh power-up.
    [main.py]
2026-07-29 web: add the browser control UI and its container image (#17)
    Moves the Web Bluetooth control page here from rasppi-utils, where it only
    lived because that repo happened to own the Pi that served it. Its actual
    counterpart is bluetooth-experimental/ — the BLE firmware it drives — so
    this is where it belongs.
    The page talks to the ESP32 directly from the browser. Whatever serves the
    file is only a file server; it never touches the hardware.
    Ships as an nginx image built for linux/arm64. The Flask server that used
    to host it existed almost entirely to generate a self-signed certificate,
    because Web Bluetooth requires a secure context. TLS is terminated by a
    reverse proxy now, so none of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
